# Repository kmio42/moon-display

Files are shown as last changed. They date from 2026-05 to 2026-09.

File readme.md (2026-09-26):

# Moon Display
The Moon Display is a compact desk device built around an ESP32-C3 and a round IPS display that shows the current view of the Moon in real time: not just the phase, but the actual appearance as seen from the observer's location at this very moment. Various display options are available, including texture choice, dimming of the unilluminated side, and whether libration is taken into account.
An internet connection is only needed as a time source — all astronomical calculations are performed on the device itself.

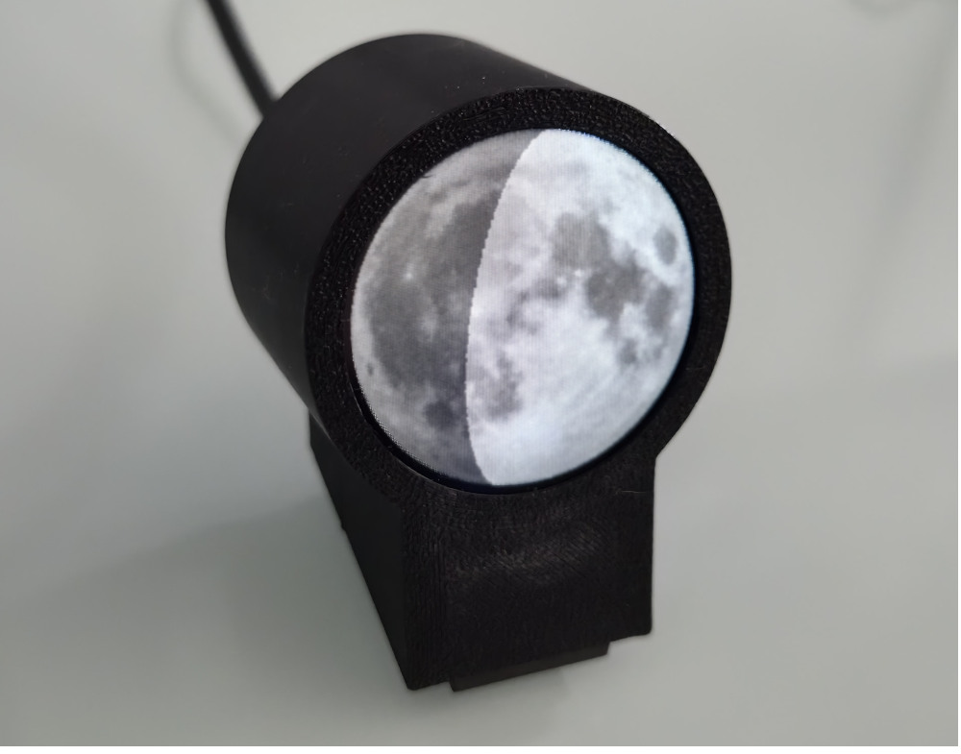
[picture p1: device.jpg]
Moon Display


## Features
* Real-time moon rendering showing the current appearance as seen from the observer's location
* Accurate moon phase, libration, and axial tilt calculation
* Parallax correction based on the observer's geographic position
* All astronomical calculations performed locally on the device using formulas from *"Astronomical Algorithms"* by Jean Meeus
* Time synchronisation via NTP — internet connection only needed as a time source
* Connects to up to 3 configured Wi-Fi networks (automatic selection by signal strength)
* Texture options: high-resolution texture from NASA's CGI Moon Kit or self-taken photograph
* Optional dimming of the unilluminated lunar side
* Optional bluish tint when the moon is below the horizon
* Second display mode: 24-hour clock with sunrise/sunset, moonrise/moonset and the time the moon is above the horizon
* Telegram bot for changing settings, querying current sun/moon coordinates and an optional daily report
* The Telegram bot's profile photo shows the current moon and is updated daily
* Serial interface (115200 baud) for settings and debug output: Julian date, RA/Dec, azimuth/altitude, libration, phase, parallactic angle, sidereal time, rotation, mask, sunrise/sunset times

## Configuration

### Wi-Fi credentials
Copy `src/credentials.h.template` to `src/credentials.h` and add your networks:

```cpp
#define WIFI_SSID_1     "Network 1"
#define WIFI_PASSWORD_1 "Password 1"

#define WIFI_SSID_2     "Network 2"
#define WIFI_PASSWORD_2 "Password 2"

#define WIFI_SSID_3     ""   // leave empty, if not used
#define WIFI_PASSWORD_3 ""
```

### Telegram bot (optional)
1. Create a bot with [@BotFather](https://t.me/BotFather) and copy the token.
2. Find your own chat ID, e.g. with [@userinfobot](https://t.me/userinfobot).
3. Add both to `src/credentials.h`:
```cpp
#define TELEGRAM_BOT_TOKEN "123456:ABC..."
#define TELEGRAM_CHAT_ID   "12345678"
```
The bot only answers messages from this chat ID. Leave the token empty to disable the bot.

| Command | Description |
|---|---|
| `/mond` | Current moon coordinates: RA/Dec, azimuth/altitude, distance, phase, libration |
| `/bild` | Current moon image as shown on the display (PNG) |
| `/profilbild` | Update the bot's profile photo now |
| `/sonne` | Current sun coordinates: RA/Dec, azimuth/altitude |
| `/bericht` | Send the daily report now |
| `/config` | Show current configuration |
| `/standort <lat> <lon>` | Set observer location in decimal degrees |
| `/optionen <value>` | Set display options bitmask (see below) |
| `/auto on\|off` | Enable or disable the daily report (auto mode) |
| `/autozeit HH:MM` | Time of the daily report (local time) |
| `/zeitzone <POSIX-TZ>` | Time zone used for all displayed times |
| `/modus mond\|uhr` | Display mode: live moon or 24-hour clock |

**Auto mode:** once a day at the configured time the bot sends a compact report, for example:
```
📅 27.09.2026

☼↑ 07:14 ☼↓ 19:05 (−2'3'')
☽↓ 08:12 ☽↑ 19:40
🌔 73% (⬈) ▅⇡
🌕🔴 28.08.
```
* `☼↑`/`☼↓`: sunrise and sunset, followed by the change of sunset time compared to the previous day (minutes'seconds'')
* `☽↑`/`☽↓`: moonrise and moonset in chronological order; events that do not occur on this day are omitted
* Moon phase symbol, illuminated fraction and `⬈` waxing / `⬊` waning
* `▁▂▃▅▇`: today's culmination height of the moon relative to the range possible at the observer's latitude (declination ±28.6° at major lunar standstill). The outer levels are narrow, so `▁`/`▇` only appear on the few days around the monthly extremes.
* `⇡`/`⇣`: tomorrow's culmination is higher/lower than today's
* Events within the next 14 days (line only present if there are any), each with its local date:
  * `🌕🔴` lunar eclipse (umbral, |β| < 0.95° at full moon), `✗` appended if the moon is below the horizon at mid-eclipse
  * `☀🌑` solar eclipse somewhere on Earth (|β| < 1.45° at new moon; local visibility is not checked)
  * `🌕＋`/`🌕－` super moon (full moon closer than 360 000 km) / mini moon (farther than 405 000 km)

Sunrise/sunset are calculated with Meeus' method, moonrise/moonset by hourly sampling of the moon's altitude with quadratic (Lagrange) interpolation of the horizon crossing, using the horizon altitude after Meeus. Full and new moon are found by bisection of the moon's elongation. All calculations are done in UT; the report covers the local calendar day (events of the UT days overlapping it are converted to local time and filtered by local date).

**Profile photo:** after start and then daily at the report time (independent of auto mode), the bot renders the current moon with the fixed display options 13 (darkened unilluminated side, NASA texture, libration), encodes it as a 240×240 JPEG on the device and sets it as its profile photo via `setMyProfilePhoto`. If an update fails, it is retried every 15 minutes. The JPEG is created in a temporary 48 KB RAM buffer; nothing is stored in flash.

### NTP server
The NTP server and UTC offset are configured in `src/MondPhase.ino`:
```cpp
constexpr char NTP_SERVER[] = "pool.ntp.org";
```

### Runtime configuration via serial interface
All runtime settings are stored in flash (NVS) and survive reboots. Connect at **115200 baud** and use the following commands:

| Command | Description |
|---|---|
| `help` | Show available commands |
| `config` | Show current configuration |
| `set_location <lat> <lon>` | Set observer location in decimal degrees (e.g. `set_location 51.0 9.0`) |
| `set_options <value>` | Set display options as a bitmask (see below) |
| `moon [HH:MM:SS \| DD.MM.YYYY HH:MM:SS]` | Show moon for given time or current time |
| `moon_run` | Start live display (updates every minute) |
| `set_time DD.MM.YYYY HH:MM:SS` | Set system time manually (UTC) |
| `wifi [on\|off]` | Enable or disable Wi-Fi |
| `mode moon\|clock` | Display mode: live moon or 24-hour clock (persistent) |
| `set_auto on\|off` | Enable or disable the daily Telegram report |
| `set_autotime HH:MM` | Time of the daily Telegram report (local time) |
| `set_timezone <POSIX-TZ>` | Time zone for displayed times (default `CET-1CEST,M3.5.0,M10.5.0/3`) |

**Display options bitmask** (combine with `+`):

| Bit | Value | Description |
|---|---|---|
| 0 | 1 | Darken unilluminated side (earthshine) |
| 1 | 2 | Bluish tint when moon is below horizon |
| 2 | 4 | Use NASA LROC texture instead of photograph |
| 3 | 8 | Apply libration |

Example: `set_options 9` enables earthshine + libration.

## Display modes

**Moon** (default): real-time rendering of the moon, updated every minute.

**24-hour clock**: midnight at the bottom, 6 am on the left, noon at the top, 6 pm on the right. All times refer to the current local calendar day.
* Light yellow hands: sunrise and sunset
* Light blue hands: moonrise and moonset; the light blue segment at the rim shows when the moon is above the horizon
* Dashed light blue hand with `+1`/`-1`: the next event of the current or upcoming moon passage that falls on the next or previous day (at most one)
* Red hand: current time
* Grey line at the bottom: day boundary (midnight)
* Centre: current moon, rendered like the moon display

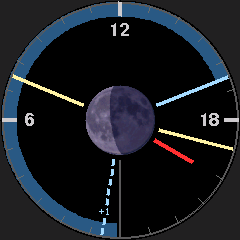
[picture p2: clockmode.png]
24-hour clock mode


## Hardware
* ESP32-C3 Super Mini
* 1.28 inch round IPS display (GC9A01)

## Software Requirements
* [VS Code](https://code.visualstudio.com/) with the [pioarduino IDE extension](https://github.com/pioarduino/platform-espressif32)
* The following libraries are fetched automatically by pioarduino:
  * `Adafruit GFX Library`
  * `Adafruit GC9A01A`
  * `SerialCommands`
  * `UniversalTelegramBot`
  * `ArduinoJson` (v6)
  * `JPEGENC` (JPEG encoder for the bot's profile photo)

## Building and Flashing
1. Clone or download this repository and open the folder in VS Code.
2. pioarduino will automatically install the required libraries on first build.
3. Copy `src/credentials.h.template` to `src/credentials.h` and fill in your Wi-Fi credentials (and optionally the Telegram bot token and chat ID).
4. Connect the ESP32-C3 via USB.
5. Click **Upload** in the pioarduino toolbar (or run `platformio run --target upload`) to build and flash the firmware.
6. Use the pioarduino **Serial Monitor** at 115200 baud to view debug output.

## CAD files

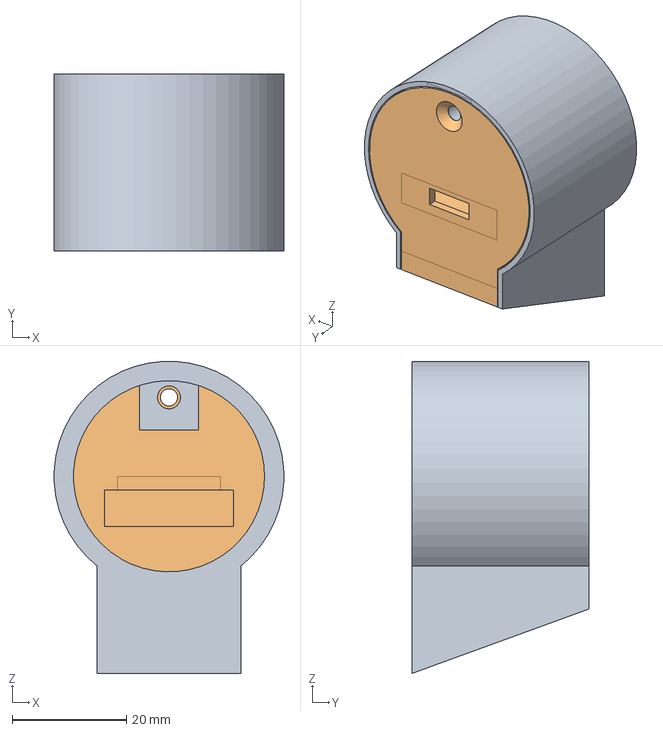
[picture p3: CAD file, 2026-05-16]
mechanics/casing_display.step
40.1 x 31.0 x 54.5 mm
Deckel

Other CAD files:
mechanics/casing_display.FCStd

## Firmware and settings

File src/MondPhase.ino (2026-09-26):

/**
 * MondPhase.ino – ESP32 Arduino Sketch
 *
 * Lädt Uhrzeit per NTP, berechnet Mond- und Sonnenposition mit astro.cpp
 * und ruft drawMoonPhase(radius=240) auf.
 *
 * Vom Nutzer zu ergänzen:
 *   - WIFI_SSID_1..3 / WIFI_PASSWORD_1..3  (in credentials.h)
 */

#include <WiFi.h>
#include <WiFiMulti.h>
#include <time.h>

#include <Adafruit_GFX.h>     // Core graphics library
#include <Adafruit_GC9A01A.h>

#include <SerialCommands.h>

// ── Konfiguration ────────────────────────────────────────────────────────────

#include "credentials.h"
#include "clock_face.h"
#include "display_mode.h"

WiFiMulti wifiMulti;

// NTP
constexpr long   GMT_OFFSET_SEC  = 0;    // UTC verwenden; Zeitzone lokal egal
constexpr int    DAYLIGHT_OFFSET = 0;
constexpr char   NTP_SERVER[]    = "pool.ntp.org";

// Mond-Rendering
extern void calculateMoon(const struct tm& timeinfo, bool printInfo, Adafruit_GC9A01A* tft);

// Persistente Konfiguration (definiert in Config.ino)
extern double configLatitude;
extern double configLongitude;
extern int    configDisplayOptions;
extern bool   configAutoMode;
extern int    configAutoTime;
extern String configTimezone;
extern int    configDisplayMode;
extern void   loadConfig();
extern void   saveConfig();
extern bool   isValidTimezone(const char* tz);
extern int    parseHHMM(const char* s);

// Telegram-Bot (definiert in Telegram.ino)
extern void setupTelegram();
extern void handleTelegram();
extern void resetAutoReportDay();

// Display
#define TFT_CS 7
#define TFT_DC 10

Adafruit_GC9A01A tft(TFT_CS, TFT_DC);

// Display-Mode
enum mode { MODE_MOON, MODE_STATIC, MODE_DISPLAY, MODE_CLOCK };
mode currentMode = MODE_MOON;

bool wifiOn = true;

// -- Serial Commands

char serial_command_buffer_[100];
SerialCommands serial_commands_(&Serial, serial_command_buffer_, sizeof(serial_command_buffer_), "\r\n", " ");

//This is the default handler, and gets called when no other command matches. 
// Note: It does not get called for one_key commands that do not match
void cmd_unrecognized(SerialCommands* sender, const char* cmd)
{
  sender->GetSerial()->print("Unrecognized command [");
  sender->GetSerial()->print(cmd);
  sender->GetSerial()->println("]");
  sender->GetSerial()->println("Type 'help' for a list of commands.");
}

bool parseDateTime(const char* arg, struct tm& tm) {
    memset(&tm, 0, sizeof(tm));
    char* parsed = strptime(arg, "%d.%m.%Y %H:%M:%S", &tm);
    if (parsed == nullptr) {
        // Nur Uhrzeit: HH:MM – aktuelles Datum übernehmen
        struct tm now;
        if (!getLocalTime(&now)) {
            return false;
        }
        tm = now;
        parsed = strptime(arg, "%H:%M:%S", &tm);
    }
    if (parsed == nullptr) {
        return false;
    }
    return true;
}

void cmd_moon(SerialCommands* sender)
{
    struct tm tm;
    const char* arg0 = sender->Next();

    if (arg0 != nullptr) {
        char datetime[50];
        // Versuche zuerst vollständiges Datum+Zeit: DD.MM.YYYY HH:MM:SS
        const char* arg1 = sender->Next();
        if (arg1 != nullptr) {
            snprintf(datetime, sizeof(datetime), "%s %s", arg0, arg1);
        } else {
            snprintf(datetime, sizeof(datetime), "%s", arg0);
        }
        if (!parseDateTime(datetime, tm)) {
            sender->GetSerial()->println("Ungültiges Format:");
            sender->GetSerial()->println(datetime);
            sender->GetSerial()->println("Erwartet: HH:MM:SS oder TT.MM.JJJJ HH:MM:SS");
            return;
        }
    } else {
        if (!getLocalTime(&tm)) {
            sender->GetSerial()->println("Keine gültige NTP-Zeit verfügbar.");
            return;
        }
    }

    sender->GetSerial()->println("Calculating moon position...");
    currentMode = MODE_STATIC;
    calculateMoon(tm, true, &tft);
    sender->GetSerial()->println("Done.");
}
SerialCommand cmd_moon_("moon", cmd_moon);

void cmd_moon_run_(SerialCommands* sender)
{
    sender->GetSerial()->println("Starting dynamic moon display...");
    setDisplayMode(DISPLAY_MODE_MOON);
}
SerialCommand cmd_moon_run("moon_run", cmd_moon_run_);

void cmd_mode_(SerialCommands* sender)
{
    const char* arg0 = sender->Next();
    if (arg0 != nullptr && strcmp(arg0, "moon") == 0) {
        setDisplayMode(DISPLAY_MODE_MOON);
    } else if (arg0 != nullptr && strcmp(arg0, "clock") == 0) {
        setDisplayMode(DISPLAY_MODE_CLOCK);
    } else {
        sender->GetSerial()->println("Ungültiges Argument. Erwartet: mode moon|clock");
        return;
    }
    sender->GetSerial()->printf("Anzeigemodus gespeichert: %s\n", displayModeName());
}
SerialCommand cmd_mode("mode", cmd_mode_);

void cmd_set_time_(SerialCommands* sender)
{
    const char* arg0 = sender->Next();
    const char* arg1 = sender->Next();
    if (arg0 == nullptr || (arg1 != nullptr && sender->Next() != nullptr)) {
        sender->GetSerial()->println("Ungültiges Format. Erwartet: TT.MM.JJJJ HH:MM:SS");
        return;
    }
    struct tm tm;
    char datetime[50];
    if (arg1 != nullptr) {
        snprintf(datetime, sizeof(datetime), "%s %s", arg0, arg1);
    }
    if (!parseDateTime(datetime, tm)) {
        sender->GetSerial()->println("Ungültiges Format. Erwartet: TT.MM.JJJJ HH:MM:SS");
        return;
    }
    time_t t = mktime(&tm);
    struct timeval now = { .tv_sec = t };
    settimeofday(&now, nullptr);
    sender->GetSerial()->println("Zeit aktualisiert.");
}
SerialCommand cmd_set_time("set_time", cmd_set_time_);

void cmd_wifi_(SerialCommands* sender)
{
    sender->GetSerial()->println("Aktuelle WLAN-Verbindungen:");
    sender->GetSerial()->print(WiFi.SSID());
    sender->GetSerial()->print(" (");
    sender->GetSerial()->print(WiFi.RSSI());
    sender->GetSerial()->println(" dBm)");

    const char *arg0 = sender->Next();
    if (arg0 != nullptr) {
        if(strcmp(arg0, "on") == 0) {
            sender->GetSerial()->println("WLAN-Verbindung aktivieren...");
            wifiOn = true;
        } else if (strcmp(arg0, "off") == 0) {
            sender->GetSerial()->println("WLAN-Verbindung trennen...");
            WiFi.disconnect(true);
            wifiOn = false;
        } else {
            sender->GetSerial()->println("Ungültiges Argument. Erwartet: on oder off");
        }
    }
}
SerialCommand cmd_wifi("wifi", cmd_wifi_);

void cmd_set_location_(SerialCommands* sender)
{
    const char* arg0 = sender->Next();
    const char* arg1 = sender->Next();
    if (arg0 == nullptr || arg1 == nullptr) {
        sender->GetSerial()->println("Ungültiges Format. Erwartet: set_location <lat> <lon>");
        return;
    }
    char* endLat = nullptr;
    char* endLon = nullptr;
    double lat = strtod(arg0, &endLat);
    double lon = strtod(arg1, &endLon);
    if (endLat == arg0 || endLon == arg1 || lat < -90.0 || lat > 90.0 || lon < -180.0 || lon > 180.0) {
        sender->GetSerial()->println("Ungültige Werte. Lat: -90..90, Lon: -180..180");
        return;
    }
    configLatitude  = lat;
    configLongitude = lon;
    saveConfig();
    requestRedraw();
    sender->GetSerial()->printf("Standort gespeichert: %.6f / %.6f\n", configLatitude, configLongitude);
}
SerialCommand cmd_set_location("set_location", cmd_set_location_);

void cmd_set_options_(SerialCommands* sender)
{
    const char* arg0 = sender->Next();
    if (arg0 == nullptr) {
        sender->GetSerial()->println("Ungültiges Format. Erwartet: set_options <wert>");
        return;
    }
    char* end = nullptr;
    long value = strtol(arg0, &end, 0); // 0 = autodetect dec/hex/oct
    if (end == arg0 || value < 0 || value > 0x7FFFFFFF) {
        sender->GetSerial()->println("Ungültiger Wert für Options.");
        return;
    }
    configDisplayOptions = (int) value;
    saveConfig();
    requestRedraw();
    sender->GetSerial()->printf("Display-Optionen gespeichert: %d\n", configDisplayOptions);
}
SerialCommand cmd_set_options("set_options", cmd_set_options_);

void cmd_set_auto_(SerialCommands* sender)
{
    const char* arg0 = sender->Next();
    if (arg0 != nullptr && strcmp(arg0, "on") == 0) {
        configAutoMode = true;
    } else if (arg0 != nullptr && strcmp(arg0, "off") == 0) {
        configAutoMode = false;
    } else {
        sender->GetSerial()->println("Ungültiges Argument. Erwartet: set_auto on|off");
        return;
    }
    saveConfig();
    resetAutoReportDay();
    sender->GetSerial()->printf("Auto-Modus gespeichert: %s\n", configAutoMode ? "an" : "aus");
}
SerialCommand cmd_set_auto("set_auto", cmd_set_auto_);

void cmd_set_autotime_(SerialCommands* sender)
{
    const char* arg0 = sender->Next();
    int minutes = (arg0 != nullptr) ? parseHHMM(arg0) : -1;
    if (minutes < 0) {
        sender->GetSerial()->println("Ungültiges Format. Erwartet: set_autotime HH:MM");
        return;
    }
    configAutoTime = minutes;
    saveConfig();
    resetAutoReportDay();
    sender->GetSerial()->printf("Berichtszeit gespeichert: %02d:%02d\n", configAutoTime / 60, configAutoTime % 60);
}
SerialCommand cmd_set_autotime("set_autotime", cmd_set_autotime_);

void cmd_set_timezone_(SerialCommands* sender)
{
    const char* arg0 = sender->Next();
    if (arg0 == nullptr || !isValidTimezone(arg0)) {
        sender->GetSerial()->println("Ungültige Zeitzone. Beispiel: set_timezone CET-1CEST,M3.5.0,M10.5.0/3");
        return;
    }
    configTimezone = arg0;
    saveConfig();
    resetAutoReportDay();
    requestRedraw();
    sender->GetSerial()->printf("Zeitzone gespeichert: %s\n", configTimezone.c_str());
}
SerialCommand cmd_set_timezone("set_timezone", cmd_set_timezone_);

void cmd_config_(SerialCommands* sender)
{
    sender->GetSerial()->println("Aktuelle Konfiguration:");
    sender->GetSerial()->printf("  Latitude:  %.6f\n", configLatitude);
    sender->GetSerial()->printf("  Longitude: %.6f\n", configLongitude);
    sender->GetSerial()->printf("  Options:   %d (0x%X)\n", configDisplayOptions, configDisplayOptions);
    sender->GetSerial()->printf("    [%c] darken_unlit    (1)\n",   (configDisplayOptions & 1) ? 'x' : ' ');
    sender->GetSerial()->printf("    [%c] bluish_tint     (2)\n",   (configDisplayOptions & 2) ? 'x' : ' ');
    sender->GetSerial()->printf("    [%c] use_nasa_model  (4)\n",   (configDisplayOptions & 4) ? 'x' : ' ');
    sender->GetSerial()->printf("    [%c] use_libration   (8)\n",   (configDisplayOptions & 8) ? 'x' : ' ');
    sender->GetSerial()->printf("  Auto-Modus: %s, täglich um %02d:%02d\n", configAutoMode ? "an" : "aus", configAutoTime / 60, configAutoTime % 60);
    sender->GetSerial()->printf("  Zeitzone:  %s\n", configTimezone.c_str());
    sender->GetSerial()->printf("  Anzeige:   %s\n", displayModeName());
}
SerialCommand cmd_config("config", cmd_config_);

void cmd_help(SerialCommands* sender)
{
  sender->GetSerial()->println("Available commands:");
  sender->GetSerial()->println("  help - Show this help message");
  sender->GetSerial()->println("  moon [HH:MM:SS | DD.MM.YYYY HH:MM:SS] - Display moon phase for given time (or current time if no argument)");
  sender->GetSerial()->println("  moon_run - Start dynamic moon display (updates every minute)");
  sender->GetSerial()->println("  mode moon|clock - Anzeigemodus: Mond oder 24h-Uhr (persistent)");
  sender->GetSerial()->println("  wifi [on|off] - Turn WiFi on or off");
  sender->GetSerial()->println("  set_time TT.MM.JJJJ HH:MM:SS - Set system time (UTC)");
  sender->GetSerial()->println("  set_location <lat> <lon> - Standort persistent speichern (Dezimalgrad)");
  sender->GetSerial()->println("  set_options <wert> - Darstellungsoptionen persistent speichern (Bitfeld)");
  sender->GetSerial()->println("    Bits: 1=darken_unlit, 2=bluish_tint, 4=use_nasa_model, 8=use_libration");
  sender->GetSerial()->println("  set_auto on|off - Täglichen Telegram-Bericht ein/aus");
  sender->GetSerial()->println("  set_autotime HH:MM - Uhrzeit des Telegram-Berichts (Lokalzeit)");
  sender->GetSerial()->println("  set_timezone <POSIX-TZ> - Zeitzone für Ausgaben, z. B. CET-1CEST,M3.5.0,M10.5.0/3");
  sender->GetSerial()->println("  config - Aktuelle Konfiguration anzeigen");
}
SerialCommand cmd_help_("help", cmd_help);

void setupSerialCommands() {
    serial_commands_.AddCommand(&cmd_help_);
    serial_commands_.AddCommand(&cmd_moon_);
    serial_commands_.AddCommand(&cmd_moon_run);
    serial_commands_.AddCommand(&cmd_mode);
    serial_commands_.AddCommand(&cmd_set_time);
    serial_commands_.AddCommand(&cmd_wifi);
    serial_commands_.AddCommand(&cmd_set_location);
    serial_commands_.AddCommand(&cmd_set_options);
    serial_commands_.AddCommand(&cmd_set_auto);
    serial_commands_.AddCommand(&cmd_set_autotime);
    serial_commands_.AddCommand(&cmd_set_timezone);
    serial_commands_.AddCommand(&cmd_config);
    serial_commands_.SetDefaultHandler(cmd_unrecognized);
}

// ── Setup & Loop ─────────────────────────────────────────────────────────────

void setup() {
    Serial.begin(115200);

    loadConfig();

    WiFi.mode(WIFI_STA);
    // WLAN verbinden (alle konfigurierten Netzwerke)
    if (strlen(WIFI_SSID_1) > 0) wifiMulti.addAP(WIFI_SSID_1, WIFI_PASSWORD_1);
    if (strlen(WIFI_SSID_2) > 0) wifiMulti.addAP(WIFI_SSID_2, WIFI_PASSWORD_2);
    if (strlen(WIFI_SSID_3) > 0) wifiMulti.addAP(WIFI_SSID_3, WIFI_PASSWORD_3);

    // NTP starten (UTC)
    configTime(GMT_OFFSET_SEC, DAYLIGHT_OFFSET, NTP_SERVER);

    tft.begin();
    tft.fillScreen(GC9A01A_BLACK);

    // Serial Commands
    setupSerialCommands();

    setupTelegram();

    requestRedraw();
}

unsigned long lastMoonCalc = 60000; // Erzwinge Berechnung direkt nach Start, da loop() erst nach 60s aktualisiert
unsigned long lastWifiCheck = 0;

long lastClockMinute = -1;

// Erzwingt ein Neuzeichnen im konfigurierten Anzeigemodus im nächsten loop()-Durchlauf.
void requestRedraw() {
    currentMode = (configDisplayMode == DISPLAY_MODE_CLOCK) ? MODE_CLOCK : MODE_MOON;
    lastMoonCalc = millis() - 60001;
    lastClockMinute = -1;
    clockFaceInvalidate();
}

// Setzt den Anzeigemodus, speichert ihn und zeichnet neu.
void setDisplayMode(int displayMode) {
    configDisplayMode = displayMode;
    saveConfig();
    requestRedraw();
}

const char* displayModeName() {
    return (configDisplayMode == DISPLAY_MODE_CLOCK) ? "Uhr" : "Mond";
}

void loop() {
    
    if (wifiOn && millis() - lastWifiCheck > 1000) {
        wifiMulti.run(1000);
        lastWifiCheck = millis();
    }

    serial_commands_.ReadSerial();
    handleTelegram();
    struct tm zeitInfo;
    if (currentMode == MODE_MOON && getLocalTime(&zeitInfo) && (millis() - lastMoonCalc > 60000)) {
        Serial.println("Updating moon display...");
        calculateMoon(zeitInfo, false, &tft);
        lastMoonCalc = millis();
    } else if (currentMode == MODE_DISPLAY) {
        // Hier könnte z.B. ein Wechsel zwischen verschiedenen Anzeigemodi implementiert werden
    } else if (currentMode == MODE_CLOCK) {
        // 24h-Uhr: einmal pro Minute aktualisieren
        time_t now = time(nullptr);
        if (now > 1700000000 && now / 60 != lastClockMinute) {
            unsigned long start = millis();
            drawClockFace(&tft, now);
            lastClockMinute = now / 60;
            Serial.printf("Uhr aktualisiert (%lu ms)\n", millis() - start);
        }
    }
    delay(100);
    //berechneSonnenaufgang();
    //berechneMondaufgang();
}

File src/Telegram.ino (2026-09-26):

/**
 * Telegram.ino – Telegram-Bot für Einstellungen, Koordinaten und Tagesbericht
 *
 * Nur Nachrichten aus TELEGRAM_CHAT_ID werden beantwortet.
 * Alle Berechnungen laufen in UT, erst die Ausgabe wird in Lokalzeit (configTimezone) umgerechnet.
 */

#include <WiFi.h>
#include <WiFiClientSecure.h>
#include <UniversalTelegramBot.h>
#include <JPEGENC.h>
#include <new>
#include <time.h>

#include "astro.h"
#include "ephemeris.h"
#include "moon_render.h"
#include "png_stream.h"
#include "display_mode.h"
#include "credentials.h"

#ifndef TELEGRAM_BOT_TOKEN
#define TELEGRAM_BOT_TOKEN ""
#endif
#ifndef TELEGRAM_CHAT_ID
#define TELEGRAM_CHAT_ID ""
#endif

// Persistente Konfiguration (definiert in Config.ino)
extern double configLatitude;
extern double configLongitude;
extern int    configDisplayOptions;
extern bool   configAutoMode;
extern int    configAutoTime;
extern String configTimezone;
extern void   saveConfig();
extern void   utcToLocal(time_t t, struct tm& out);
extern bool   isValidTimezone(const char* tz);
extern int    parseHHMM(const char* s);

// Display neu zeichnen (definiert in MondPhase.ino)
extern void requestRedraw();
extern void setDisplayMode(int displayMode);
extern const char* displayModeName();
extern int configDisplayMode;

constexpr unsigned long TELEGRAM_POLL_INTERVAL = 3000;  // ms
constexpr time_t        MIN_VALID_TIME         = 1700000000; // Zeit gilt erst nach NTP-Sync als gültig

static WiFiClientSecure telegramClient;
static UniversalTelegramBot bot(TELEGRAM_BOT_TOKEN, telegramClient);
static bool telegramEnabled = false;
static bool telegramCommandsSet = false;
static unsigned long lastTelegramPoll = 0;
static int lastReportDay = -1;  // Lokaler Tag (Jahr*1000 + Tag im Jahr) des letzten Tagesberichts
static int lastProfileDay = -1; // Lokaler Tag des letzten Profilbilds, -1: seit dem Start keins
static unsigned long lastProfileAttempt = 0;

// ── Formatierung ─────────────────────────────────────────────────────────────

// Formatiert eine UTC-Zeit als lokale Uhrzeit "HH:MM".
static String formatLocalTime(time_t t) {
    struct tm lt;
    utcToLocal(t, lt);
    char buf[8];
    snprintf(buf, sizeof(buf), "%02d:%02d", lt.tm_hour, lt.tm_min);
    return buf;
}

// Formatiert eine UTC-Zeit als lokales Datum "TT.MM.".
static String formatLocalDate(time_t t) {
    struct tm lt;
    utcToLocal(t, lt);
    char buf[8];
    snprintf(buf, sizeof(buf), "%02d.%02d.", lt.tm_mday, lt.tm_mon + 1);
    return buf;
}

static String formatDeg(double rad) {
    char buf[16];
    snprintf(buf, sizeof(buf), "%+.2f°", rad * astro::RAD2DEG);
    return buf;
}

static String formatRa(double rad) {
    double h = fmod(rad * astro::RAD2DEG / 15.0 + 24.0, 24.0);
    int hh = (int) h;
    int mm = (int) ((h - hh) * 60.0);
    int ss = (int) (((h - hh) * 60.0 - mm) * 60.0);
    char buf[16];
    snprintf(buf, sizeof(buf), "%02dh %02dm %02ds", hh, mm, ss);
    return buf;
}

// Azimut in astro.cpp wird nach Meeus von Süden gezählt; für die Ausgabe ab Norden (N=0°, O=90°).
static String formatAzimut(double rad) {
    char buf[16];
    snprintf(buf, sizeof(buf), "%.1f°", fmod(rad * astro::RAD2DEG + 540.0, 360.0));
    return buf;
}

static String formatNow() {
    struct tm lt;
    utcToLocal(time(nullptr), lt);
    char buf[32];
    strftime(buf, sizeof(buf), "%d.%m.%Y %H:%M", &lt);
    return buf;
}

static bool currentUtc(struct tm& utc) {
    time_t now = time(nullptr);
    if (now < MIN_VALID_TIME) return false;
    gmtime_r(&now, &utc);
    return true;
}

// ── Nachrichten ──────────────────────────────────────────────────────────────

String buildDailyReport() {
    struct tm utc;
    if (!currentUtc(utc)) return "Keine gültige Uhrzeit (NTP) verfügbar.";

    time_t now = time(nullptr);
    struct tm lt;
    utcToLocal(now, lt);
    const time_t dayStart = now - (lt.tm_hour * 3600 + lt.tm_min * 60 + lt.tm_sec);

    DayEvents today     = eventsForLocalDay(now, true);
    DayEvents yesterday = eventsForLocalDay(dayStart - 1, false);
    SkyState sky = computeSky(utc);

    char buf[64];
    strftime(buf, sizeof(buf), "📅 %d.%m.%Y", &lt);
    String msg = buf;
    msg += "\n\n";

    if (today.sunValid) {
        msg += "☼\uFE0E↑ ";
        msg += today.hasSunrise ? formatLocalTime(today.sunrise) : String("-");
        msg += "\u2003☼\uFE0E↓ ";
        msg += today.hasSunset ? formatLocalTime(today.sunset) : String("-");
        if (today.hasSunset && yesterday.hasSunset) {
            // Astronomische Differenz, unabhängig von einer Sommerzeitumstellung
            long sec = (long) (today.sunset - yesterday.sunset) - 86400L;
            long absSec = labs(sec);
            snprintf(buf, sizeof(buf), " (%s%ld'%ld'')", sec < 0 ? "−" : "+", absSec / 60, absSec % 60);
            msg += buf;
        }
        msg += "\n";
    } else {
        msg += "☀\n";
    }

    // Mondauf-/untergang in zeitlicher Reihenfolge, fehlende Ereignisse weglassen
    String rise = today.hasMoonrise ? "☽↑ " + formatLocalTime(today.moonrise) : String();
    String set  = today.hasMoonset  ? "☽↓ " + formatLocalTime(today.moonset)  : String();
    bool setFirst = today.hasMoonrise && today.hasMoonset && today.moonset < today.moonrise;
    String first  = setFirst ? set : rise;
    String second = setFirst ? rise : set;
    msg += first;
    if (first.length() && second.length()) msg += "\u2003";
    msg += second;
    if (!first.length() && !second.length()) msg += "☽-";
    msg += "\n";
    // Phase, Kulminationshöhe als Balken und deren Tendenz
    static const char* const HEIGHT_BARS[] = {"▁", "▂", "▃", "▅", "▇"};
    MoonOutlook outlook = moonOutlookFor(now);
    snprintf(buf, sizeof(buf), "%s %.0f%% (%s)\u2003%s%s",
             moonPhaseEmoji(sky.phase, sky.waxing), sky.phase * 100.0, sky.waxing ? "⬈" : "⬊",
             HEIGHT_BARS[outlook.heightLevel], outlook.heightRising ? "⇡" : "⇣");
    msg += buf;

    // Finsternisse und Super-/Minimond der nächsten 14 Tage
    String events;
    if (outlook.lunarEclipse) {
        events += String(" 🌕🔴") + (outlook.lunarEclipseVisible ? "" : "✗") + " " + formatLocalDate(outlook.fullMoon);
    }
    if (outlook.solarEclipse) {
        events += " ☀🌑 " + formatLocalDate(outlook.newMoon);
    }
    if (outlook.superMoon) {
        events += " 🌕＋ " + formatLocalDate(outlook.fullMoon);
    }
    if (outlook.miniMoon) {
        events += " 🌕－ " + formatLocalDate(outlook.fullMoon);
    }
    if (events.length()) {
        msg += "\n" + events.substring(1);
    }
    return msg;
}
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

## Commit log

2026-04-22 bugfix nullpointer exception, wifi improvement
    [MondPhase.ino]
2026-05-16 add casing
    [casing_display.FCStd, casing_display.step]
2026-09-26 add telegram bot
    Telegram bot to change settings, query current sun/moon coordinates and
    send a daily report (auto mode) with sunrise/sunset, sunset difference to
    the previous day, moonrise/moonset and moon phase for the local day.
    Moonrise/moonset, transit and maximum altitude are computed by hourly
    sampling of the moon's altitude with quadratic (Lagrange) interpolation.
2026-09-26 moon rise/set: single-pass sampling, detect grazing within one hour
    Compute rise/set, transit and maximum altitude in one loop over a sliding
    window of three hourly samples. Detect rise and set within the same hour
    when the parabola's vertex crosses the horizon without a sign change at
    the samples.
2026-09-26 add /bild command to send the current moon image via telegram
    The moon is rendered line by line while uploading and streamed as an
    uncompressed PNG, so no image buffer is needed. Pixel rendering moved from
    drawMoon into moon_render.cpp and is shared by display and telegram.
2026-09-26 add 24h clock display mode
    Clock face with midnight at the bottom showing sunrise/sunset and
    moonrise/moonset of the local calendar day, the time the moon is above
    the horizon as a segment, the current time and the moon phase in the
    centre. An event of the current or next moon passage on another date is
    shown as a dashed hand labelled +1/-1. Switch via /modus or serial
    "mode"; the mode is stored persistently.
2026-09-26 clock: partial updates for moon symbol and current-time hand
    Redraw the moon symbol in place every 5 minutes (aligned to :00/:05/...)
    and when the moon crosses the horizon. When the red hand moves, only the
    elements it may have covered are redrawn. A full redraw now happens only
    on start, day change or when hands/segment change, which also fixes a
    stale dashed line after a moonrise/moonset.
2026-09-26 telegram: compact daily report with symbols
    Sun and moon events as short symbol lines, moon rise/set sorted by time
    and missing events omitted, moon phase as emoji, percentage and a
    waxing/waning arrow without emoji presentation.
    [Telegram.ino]
2026-09-26 telegram: set the bot's profile photo to the current moon
    Renders the moon with fixed options 13 (darken unlit, NASA texture,
    libration), encodes it as JPEG with JPEGENC and uploads it via
    setMyProfilePhoto. Updated after start, daily at report time and with
    the new /profilbild command.
    [Telegram.ino]
2026-10-03 moon: options to ignore parallactic and position angle; tint only with bit 2
    New display option bits: 16 ignores the parallactic angle (celestial
    north up instead of zenith), 32 ignores the position angle of the
    moon's axis (lunar north pole up). The terminator is rotated together
    with the texture, so the lit features stay correct. Both are "ignore"
    bits, so stored option values keep their current look.
    The bluish tint below the horizon was applied regardless of the
    options; it now requires bit 2 as documented.
2026-10-03 telegram: serve a group with daily report and moon group photo
    With TELEGRAM_GROUP_ID set, the bot posts the daily report to the group
    and sets the current moon as group photo (setChatPhoto) daily at the
    report time, together with the profile photo. Each target is retried
    separately so the group gets no duplicate photo notices.
    Commands are accepted only from the user TELEGRAM_CHAT_ID, in the
    private chat or the group; in the group, plain messages and commands
    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
2026-10-09 config: fix heap leak in utcToLocal from setenv("TZ")
    newlib's setenv() does not free the old value when the new one is longer.
    utcToLocal() switched TZ between configTimezone and "UTC0" on every call,
    losing about 45 bytes each time. The report and profile photo checks call
    it every 3 s, so the heap ran empty after 1-2 hours: first TLS to Telegram
    failed, then the WiFi task aborted in esp_timer_create (panic, reboot).
    TZ now gets a buffer of TZ_CAPACITY characters once, which is overwritten
    in place. /zeitzone rejects strings that do not fit.
2026-10-09 telegram: log heap every minute and keep it across a crash
    The heap state is printed to serial once per minute and stored in RTC
    memory, which survives a panic. After a reset /status and the crash
    notification show the state before the reset.
2026-10-10 astro: Horner-Schema, gemeinsame Fundamentalargumente, Einheiten und Kapitelübersicht
    - Polynome über static inline horner() mit Koeffizienten in Buchreihenfolge
    - Fundamentalargumente von Sonne (Kap. 24) und Mond (Kap. 45) nur noch einmal
    - Tabellen 45.1/45.2 als typisierte Terme statt double-Arrays mit Casts
    - const-Parameter, keine Out-Parameter, Rückgaben mit Designated Initializers
    - calculateJulianDate(year, month, day, hours) ohne Default-Argumente
    - Einheit in jedem Kommentar, Kapitelübersicht (umgesetzt / nicht umgesetzt) in astro.h
    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
2026-10-10 astro: Namen vereinheitlichen
    Typen, Felder und Funktionen tragen durchgängig englische Fachbegriffe,
    z. B. RaDek → Equatorial {ra, dec}, AzimutHeight → Horizontal {azimuth, altitude},
    MoonAxle → MoonOrientation {libration, positionAngle}, calculateJulianEpoch →
    calculateJulianCenturies, calculateRisingKnotMoon → calculateMoonAscendingNode,
    calculateMoonPhase → calculateMoonIlluminatedFraction. Aufrufer angepasst;
    Ergebnisse unverändert.
2026-10-10 astro: fachliche Korrekturen nach der deutschen 2. Auflage
    - Schiefe der Ekliptik des Datums (21.2) statt fester J2000-Konstante:
    calculateEquatorial(λ, β, ε), auch für den Positionswinkel der Mondachse
    - Entfernung Erde–Sonne nach 24.5 mit Exzentrizität des Datums; ephemeris nutzt
    sie statt fest 1 AE für den beleuchteten Teil der Mondscheibe
    - L0 der Sonne nach 24.2 (vorher Werte aus 27.2 mit Tippfehler), Zeitgleichung
    mit L0 nach 27.2 und ohne Aberrationskonstante, da α geometrisch ist
    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
2026-10-10 astro: allgemeine Datentypen für Sonne, Mond und Bahnen
    - Ecliptic {longitude, latitude, distance [km]} für Sonne und Mond;
    calculateSunPosition ersetzt calculateSunLongitude/calculateEarthSunDistance,
    calculateEquatorial nimmt Ecliptic
    - RiseTransitSet für Auf-/Untergang, Durchgang und höchsten Stand von Sonne
    (calculateSunRiseSet, Kap. 14) und Mond; gleiche Parameterreihenfolge (Länge, Breite)
    - Selenographic statt Libration (Libration = selenografische Koordinaten der Erde)
    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
2026-10-10 astro: GeoLocation für den Beobachtungsort, aboveAtStart entfernt
    - astro::GeoLocation {longitude, latitude [rad], timezone (POSIX-TZ)}; die Zeitzone
    wird nur mitgeführt, die Bibliothek rechnet weiter in UT
    - calculateSunRiseSet/calculateMoonRiseSet nehmen GeoLocation,
    neue calculateLocalSiderealTime(jd, location)
    - RiseTransitSet ohne aboveAtStart: ohne Auf- und Untergang entscheidet maxAltitude > 0
    - configLatitude/configLongitude/configTimezone → configLocation (im Flash weiter in Grad)
    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
2026-10-10 docs: ARCHITECTURE auf Englisch, deutsche Fassung als ARCHITECTURE.de.md
    Wie bei der readme: ARCHITECTURE.md englisch, ARCHITECTURE.de.md
    deutsch, gegenseitig verlinkt. Verweis auf die Zugriffsregeln korrigiert
    (steht oben), Hinweis auf die gemeinsamen Header commands.h und
    messages.h ergänzt.
